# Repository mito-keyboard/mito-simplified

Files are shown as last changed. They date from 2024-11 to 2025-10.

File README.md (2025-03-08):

# Mito PCB

The pcb for my [custom keyboard](https://github.com/KOEGlike/mito)

## Sponsor

Much thanks to pcbway for sponsoring this project, the video is in the making, stay tuned! The PCBs and stencil are very high quality!!

## Gallery

back of pcb
back of pcb with nrf52833

## Name

Inspired by the mitosis of cells

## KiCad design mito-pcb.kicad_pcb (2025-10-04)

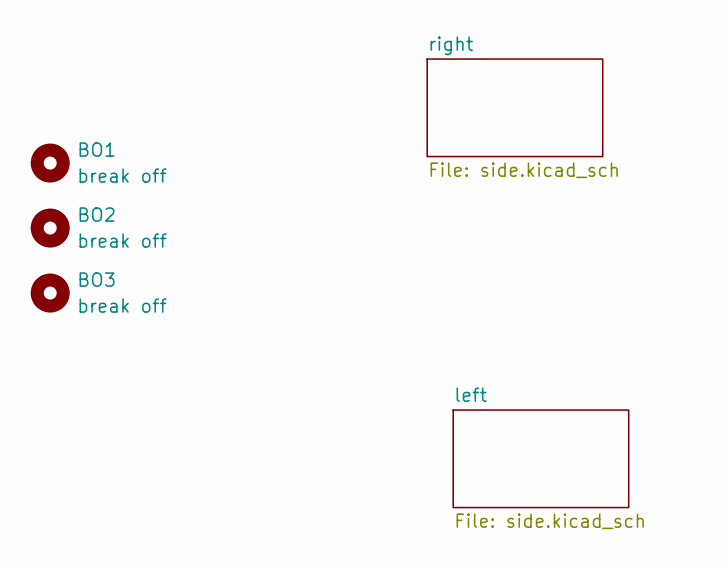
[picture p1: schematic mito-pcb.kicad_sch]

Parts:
BO1, BO2, BO3: break off; mouse-bite-2mm-slot

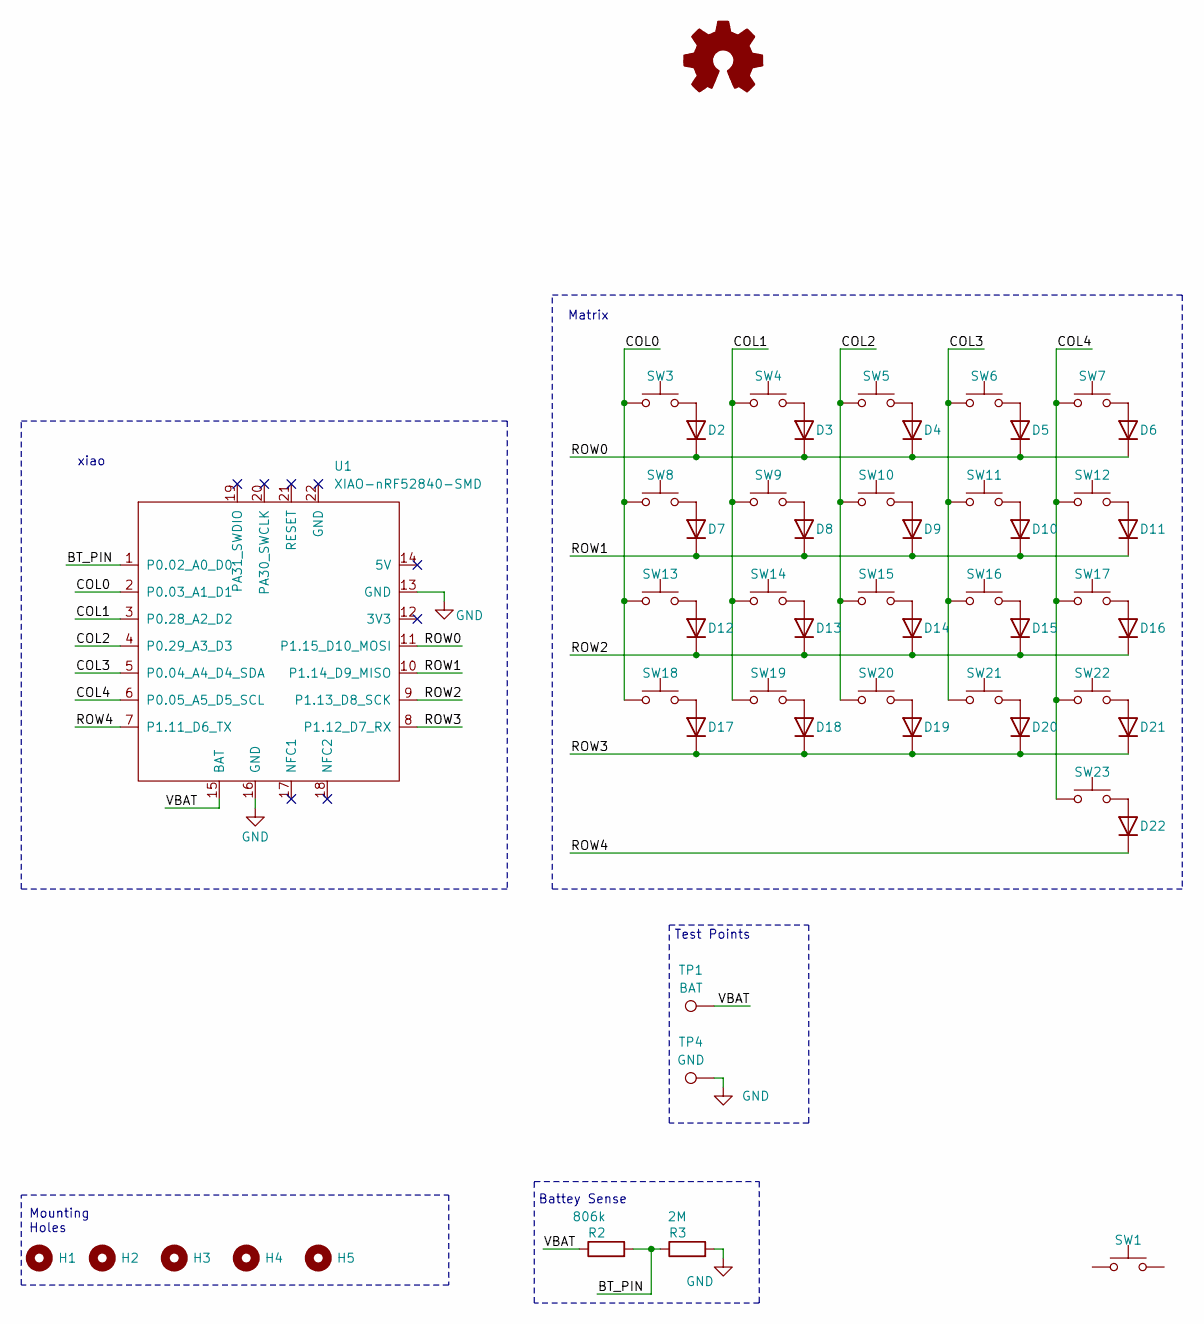
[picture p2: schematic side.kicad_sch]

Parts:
D2, D3, D4, D5, D6, D7, D8, D9, D10, D11, D12, D13, D14, D15, D16, D17, D18, D19, D20, D21, D22: 1N5819; D_SOD-123; LCSC C963381
H1, H2, H3, H4, H5: MountingHole; MountingHole_2mm
LOGO1: Logo_Open_Hardware_Small; BM logo
R2: 806k; R_0805_2012Metric; LCSC C3016043
R3: 2M; R_0805_2012Metric; LCSC C11512
SW1, SW3, SW4, SW5, SW6, SW7, SW8, SW9, SW10, SW11, SW12, SW13, SW14, SW15, SW16, SW17, SW18, SW19, SW20, SW21, SW22, SW23: SW_Push; SW_choc_v1_HS_CPG135001S30_1u; LCSC C5333465
TP1: BAT; TestPoint_Pad_D2.0mm
TP4: GND; TestPoint_Pad_D2.0mm
U1: XIAO-nRF52840-SMD; modified-XIAO-nRF52840-SMD

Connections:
/left/BT_PIN: R2.2, R3.1, U1.1 (P0.02_A0_D0)
/left/COL0: SW3.1, SW8.1, SW13.1, SW18.1, U1.2 (P0.03_A1_D1)
/left/COL1: SW4.1, SW9.1, SW14.1, SW19.1, U1.3 (P0.28_A2_D2)
/left/COL2: SW5.1, SW10.1, SW15.1, SW20.1, U1.4 (P0.29_A3_D3)
/left/COL3: SW6.1, SW11.1, SW16.1, SW21.1, U1.5 (P0.04_A4_D4_SDA)
/left/COL4: SW7.1, SW12.1, SW17.1, SW22.1, SW23.1, U1.6 (P0.05_A5_D5_SCL)
/left/ROW0: D2.1 (K), D3.1 (K), D4.1 (K), D5.1 (K), D6.1 (K), U1.11 (P1.15_D10_MOSI)
/left/ROW1: D7.1 (K), D8.1 (K), D9.1 (K), D10.1 (K), D11.1 (K), U1.10 (P1.14_D9_MISO)
/left/ROW2: D12.1 (K), D13.1 (K), D14.1 (K), D15.1 (K), D16.1 (K), U1.9 (P1.13_D8_SCK)
/left/ROW3: D17.1 (K), D18.1 (K), D19.1 (K), D20.1 (K), D21.1 (K), U1.8 (P1.12_D7_RX)
/left/ROW4: D22.1 (K), U1.7 (P1.11_D6_TX)
/left/VBAT: R2.1, TP1.1, U1.15 (BAT)
GND: R3.2, TP4.1, U1.13 (GND), U1.16 (GND); also elsewhere on the board
unnamed: D2.2 (A), SW3.2
unnamed: D3.2 (A), SW4.2
unnamed: D4.2 (A), SW5.2
unnamed: D5.2 (A), SW6.2
unnamed: D6.2 (A), SW7.2
unnamed: D7.2 (A), SW8.2
unnamed: D8.2 (A), SW9.2
unnamed: D9.2 (A), SW10.2
unnamed: D10.2 (A), SW11.2
unnamed: D11.2 (A), SW12.2
unnamed: D12.2 (A), SW13.2
unnamed: D13.2 (A), SW14.2
unnamed: D14.2 (A), SW15.2
unnamed: D15.2 (A), SW16.2
unnamed: D16.2 (A), SW17.2
unnamed: D17.2 (A), SW18.2
unnamed: D18.2 (A), SW19.2
unnamed: D19.2 (A), SW20.2
unnamed: D20.2 (A), SW21.2
unnamed: D21.2 (A), SW22.2
unnamed: D22.2 (A), SW23.2

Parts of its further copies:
D44, D45, D46, D47, D48, D49, D50, D51, D52, D53, D54, D55, D56, D57, D58, D59, D60, D61, D62, D63, D64: 1N5819; D_SOD-123; LCSC C963381
H6, H7, H8, H9, H10: MountingHole; MountingHole_2mm
R9: 806k; R_0805_2012Metric; LCSC C3016043
R10: 2M; R_0805_2012Metric; LCSC C11512
SW26, SW27, SW28, SW29, SW30, SW31, SW32, SW33, SW34, SW35, SW36, SW37, SW38, SW39, SW40, SW41, SW42, SW43, SW44, SW45, SW46: SW_Push; SW_choc_v1_HS_CPG135001S30_1u; LCSC C5333465
TP2: BAT; TestPoint_Pad_D2.0mm
TP8: GND; TestPoint_Pad_D2.0mm
U3: XIAO-nRF52840-SMD; modified-XIAO-nRF52840-SMD

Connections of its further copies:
/right/BT_PIN: R9.2, R10.1, U3.1 (P0.02_A0_D0)
/right/COL0: SW26.1, SW31.1, SW36.1, SW41.1, U3.2 (P0.03_A1_D1)
/right/COL1: SW27.1, SW32.1, SW37.1, SW42.1, U3.3 (P0.28_A2_D2)
/right/COL2: SW28.1, SW33.1, SW38.1, SW43.1, U3.4 (P0.29_A3_D3)
/right/COL3: SW29.1, SW34.1, SW39.1, SW44.1, U3.5 (P0.04_A4_D4_SDA)
/right/COL4: SW30.1, SW35.1, SW40.1, SW45.1, SW46.1, U3.6 (P0.05_A5_D5_SCL)
/right/ROW0: D44.1 (K), D45.1 (K), D46.1 (K), D47.1 (K), D48.1 (K), U3.11 (P1.15_D10_MOSI)
/right/ROW1: D49.1 (K), D50.1 (K), D51.1 (K), D52.1 (K), D53.1 (K), U3.10 (P1.14_D9_MISO)
/right/ROW2: D54.1 (K), D55.1 (K), D56.1 (K), D57.1 (K), D58.1 (K), U3.9 (P1.13_D8_SCK)
/right/ROW3: D59.1 (K), D60.1 (K), D61.1 (K), D62.1 (K), D63.1 (K), U3.8 (P1.12_D7_RX)
/right/ROW4: D64.1 (K), U3.7 (P1.11_D6_TX)
/right/VBAT: R9.1, TP2.1, U3.15 (BAT)
GND: R10.2, TP8.1, U3.13 (GND), U3.16 (GND); also elsewhere on the board
unnamed: D44.2 (A), SW26.2
unnamed: D45.2 (A), SW27.2
unnamed: D46.2 (A), SW28.2
unnamed: D47.2 (A), SW29.2
unnamed: D48.2 (A), SW30.2
unnamed: D49.2 (A), SW31.2
unnamed: D50.2 (A), SW32.2
unnamed: D51.2 (A), SW33.2
unnamed: D52.2 (A), SW34.2
unnamed: D53.2 (A), SW35.2
unnamed: D54.2 (A), SW36.2
unnamed: D55.2 (A), SW37.2
unnamed: D56.2 (A), SW38.2
unnamed: D57.2 (A), SW39.2
unnamed: D58.2 (A), SW40.2
unnamed: D59.2 (A), SW41.2
unnamed: D60.2 (A), SW42.2
unnamed: D61.2 (A), SW43.2
unnamed: D62.2 (A), SW44.2
unnamed: D63.2 (A), SW45.2
unnamed: D64.2 (A), SW46.2

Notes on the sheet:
Battey Sense
Matrix
Mounting Holes
Test Points
xiao

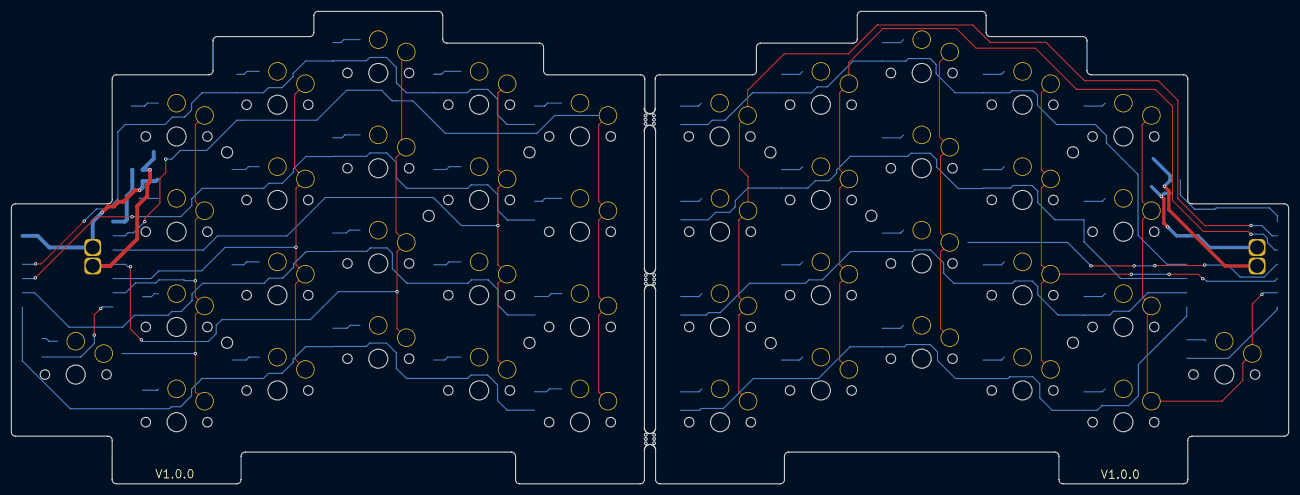
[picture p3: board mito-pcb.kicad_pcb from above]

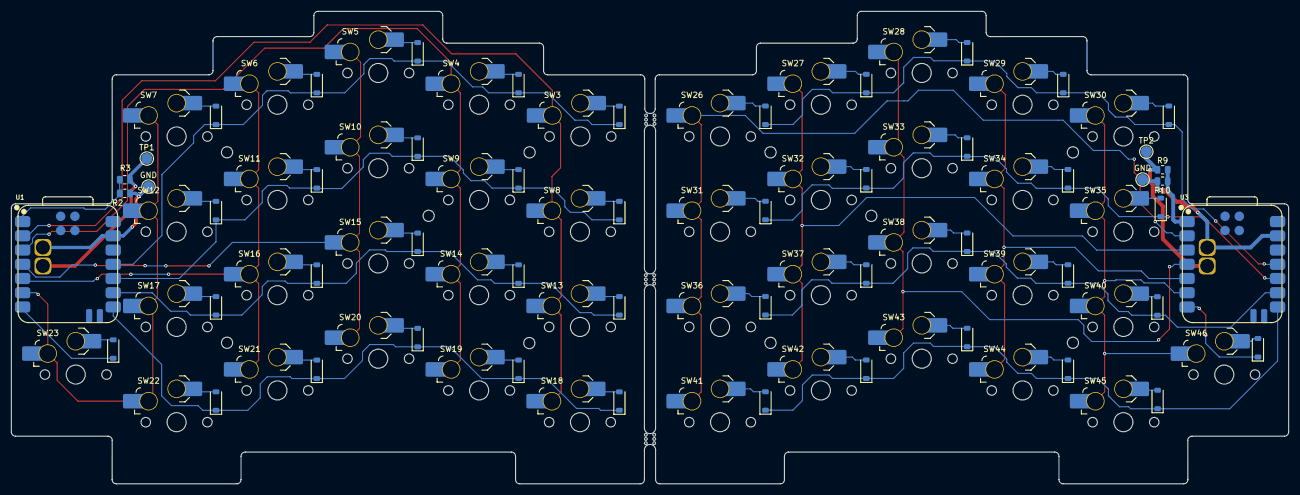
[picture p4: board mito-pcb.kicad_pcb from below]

Board: 2 copper layers, 228.0 x 84.3 mm, 107 parts (99 on the bottom side), 67 nets.

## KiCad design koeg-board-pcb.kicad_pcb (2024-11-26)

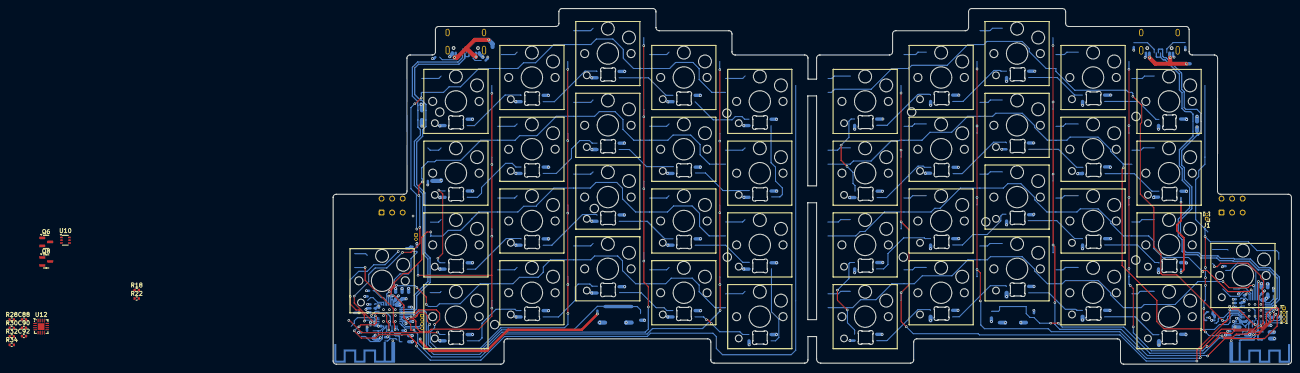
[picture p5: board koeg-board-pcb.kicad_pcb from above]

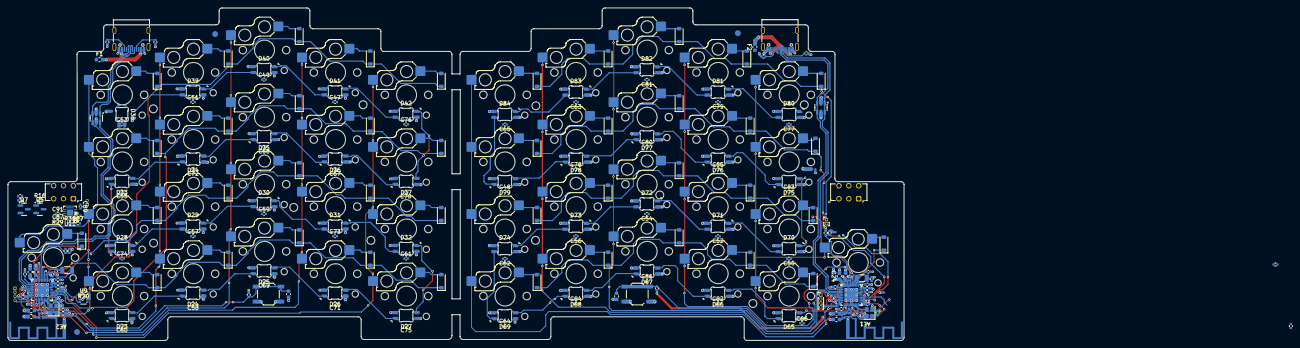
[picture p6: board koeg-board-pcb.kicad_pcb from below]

Board: 4 copper layers, 227.1 x 84.3 mm, 277 parts (215 on the bottom side), 173 nets.

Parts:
AE1: PCB_Antenna; flipped_pcb_antenna
AE2: PCB_Antenna; pcb_antenna
C2, C18: 100nF; C_0603_1608Metric
C4, C20, C41, C42, C43, C44, C47, C48, C49, C50, C51, C52, C53, C54, C55, C56, C57, C58, C59, C60, C61, C62, C63, C64, C65, C66, C67, C68, C69, C70, C71, C72, C73, C74, C75, C76, C77, C78, C79, C80, C81, C82, C83, C84, C85, C86: 100nF; C_0402_1005Metric
C5, C21: 100pF; C_0402_1005Metric
C6, C22: 820pF; C_0402_1005Metric
C7, C23, C39, C40: 1uF; C_0402_1005Metric
C9, C25, C87, C88, C89, C90, C91, C92: 4.7uF; C_0402_1005Metric
C10, C19, C24, C26: 4.7uF; C_0603_1608Metric
C11, C12, C15, C16, C27, C28, C31, C32: 12pF; C_0402_1005Metric
C13, C29: 1pF; C_0603_1608Metric
C14, C30: 1.2pF; C_0603_1608Metric
D2, D3, D4, D5, D6, D7, D8, D9, D10, D11, D12, D13, D14, D15, D16, D17, D18, D19, D20, D21, D22, D44, D45, D46, D47, D48, D49, D50, D51, D52, D53, D54, D55, D56, D57, D58, D59, D60, D61, D62, D63, D64: 1N5819; D_SOD-123
D23, D24, D25, D26, D27, D28, D29, D30, D31, D32, D33, D34, D35, D36, D37, D38, D39, D40, D41, D42, D65, D66, D67, D68, D69, D70, D71, D72, D73, D74, D75, D76, D77, D78, D79, D80, D81, D82, D83, D84: SK6812MINI-E; LED_6028R
F1, F2: 500mA; Fuse_0603_1608Metric
FID1, FID2, FID3: Fiducial; Fiducial_1.5mm_Mask3mm
H1, H2, H3, H4, H5, H6, H7, H8, H9, H10: MountingHole; MountingHole_2mm
J1, J4: Conn_01x02; PinHeader_1x02_P1.00mm_Vertical
J2, J5: SWD_Connector; PinHeader_1x04_P1.00mm_Vertical
J3, J6: USB_C_Receptacle_USB2.0_16P; USB_C_Receptacle_G-Switch_GT-USB-7010ASV
L4, L9: 4.7nH; L_0402_1005Metric
L5, L10: 2.2nH; L_0402_1005Metric
Q5, Q6: AO3401A; SOT-23
Q7, Q8: 2N7002; SOT-23
R1, R8: 100K; R_0402_1005Metric
R2, R9: 806k; R_0402_1005Metric
R3, R10: 2M; R_0402_1005Metric
R4, R5, R11, R12: 5.1k; R_0402_1005Metric
R6, R7: 100R; R_0402_1005Metric
R13, R14, R16, R18, R20, R22: 10k; R_0402_1005Metric
R27, R28: 3.9k; R_0402_1005Metric
R29, R30, R31, R32, R33, R34: 1.5k; R_0402_1005Metric
SW1, SW24: Reset Button; SW_SPST_TL3342
SW2, SW25: SW_On_Off; SW_CK_JS202011AQN_DPDT_Angled
SW3, SW4, SW5, SW6, SW7, SW8, SW9, SW10, SW11, SW12, SW13, SW14, SW15, SW16, SW17, SW18, SW19, SW20, SW21, SW22, SW26, SW27, SW28, SW29, SW30, SW31, SW32, SW33, SW34, SW35, SW36, SW37, SW38, SW39, SW40, SW41, SW42, SW43, SW44, SW45: SW_Push; SW_Hotswap_Kailh_Choc_V1V2_1.00u
SW23, SW46: SW_Push; SW_Hotswap_Kailh_Choc_V1V2_1.75u_90deg
U2, U5: USBLC6-2SC6; SOT-23-6
U7, U8: nRF52833_QDxx; QFN-40-1EP_5x5mm_P0.4mm_EP3.6x3.6mm
U9, U10: TXB0101DCK; SOT-363_SC-70-6
U11, U12: BQ24075RGT; VQFN-16-1EP_3x3mm_P0.5mm_EP1.6x1.6mm
Y1, Y2: 32MHz; Crystal_SMD_2520-4Pin_2.5x2.0mm
Y3, Y4: 32.768 kHz; Crystal_SMD_3215-2Pin_3.2x1.5mm

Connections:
/left/ANT: AE2.2 (PCB_Trace), C13.2, L4.1, L5.2, U7.24 (ANT)
/left/BT_PIN: R2.2, R3.1, U7.6 (P1.09)
/left/CC1: J3.A5 (CC1), R4.1
/left/CC2: J3.B5 (CC2), R5.1
/left/COL0: SW3.2, SW8.2, SW13.2, SW18.2, U7.34 (AIN5/P0.29)
/left/COL1: SW4.2, SW9.2, SW14.2, SW19.2, U7.7 (P0.11)
/left/COL2: SW5.2, SW10.2, SW15.2, SW20.2, U7.14 (P0.15)
/left/COL3: SW6.2, SW11.2, SW16.2, SW21.2, U7.15 (P0.17)
/left/COL4: SW7.2, SW12.2, SW17.2, SW22.2, SW23.2, U7.17 (P0.20)
/left/DEC1: C4.1, U7.1 (DEC1)
/left/DEC3: C5.1, U7.27 (DEC3)
/left/DEC4-6: C7.1, U7.26 (DEC6), U7.38 (DEC4)
/left/DEC5: C6.1, U7.21 (DEC5)
/left/DECUSB: C9.1, U7.11 (DECUSB)
/left/LED_EN: R6.1, U7.35 (AIN6/P0.30)
/left/LED_PIN: U7.33 (AIN4/P0.28), U9.3 (A)
/left/RESET: C2.2, R1.2, SW1.1, U7.16 (P0.18/~RESET)
/left/ROW0: D2.1 (K), D3.1 (K), D4.1 (K), D5.1 (K), D6.1 (K), U7.32 (AIN0/P0.02)
/left/ROW1: D7.1 (K), D8.1 (K), D9.1 (K), D10.1 (K), D11.1 (K), U7.31 (AIN1/P0.03)
/left/ROW2: D12.1 (K), D13.1 (K), D14.1 (K), D15.1 (K), D16.1 (K), U7.4 (AIN2/P0.04)
/left/ROW3: D17.1 (K), D18.1 (K), D19.1 (K), D20.1 (K), D21.1 (K), U7.5 (AIN3/P0.05)
/left/ROW4: D22.1 (K), U7.22 (NFC1/P0.09)
/left/SWDCLK: J2.4, U7.20 (SWDCLK)
/left/SWDIO: J2.3, U7.19 (SWDIO)
/left/USB_D+: J3.A6 (D+), J3.B6 (D+), U2.3 (I/O2), U2.4 (I/O2), U7.13 (D+)
/left/USB_D-: J3.A7 (D-), J3.B7 (D-), U2.1 (I/O1), U2.6 (I/O1), U7.12 (D-)
/left/VBAT: C89.2, J1.1, R2.1, U11.2 (BAT), U11.3 (BAT)
/left/VBUS: C87.2, F1.1, U2.5 (VBUS), U11.13 (IN)
/left/VSW: C19.1, Q5.3 (D), R16.2, SW2.2 (B), U7.9 (VDDH), U7.10 (VBUS), U9.6 (V_{CCB}), U11.6 (EN1)
/left/V_SYS: C10.2, C39.2, C41.2, C43.2, J2.2, R1.1, R20.2, U7.8 (VDD), U7.18 (VDD), U7.30 (VDD), U7.40 (VDD), U9.1 (V_{CCA})
/left/XC1: C11.1, U7.28 (XC1), Y1.1
/left/XC2: C12.1, U7.29 (XC2), Y1.3
/left/XL1: C31.2, U7.2 (XL1/P0.00), Y3.2
/left/XL2: C15.2, U7.3 (XL2/P0.01), Y3.1
/left/leds/DATA: D23.3 (DIN), U9.4 (B)
/left/leds/LED_PWR: C47.2, C49.2, C51.2, C53.2, C55.2, C57.2, C58.2, C59.2, C60.2, C61.2, C67.2, C68.2, C69.2, C70.2, C71.2, C72.2, C73.2, C74.2, C75.2, C76.2, D23.1 (VDD), D24.1 (VDD), D25.1 (VDD), D26.1 (VDD), D27.1 (VDD), D28.1 (VDD), D29.1 (VDD), D30.1 (VDD), D31.1 (VDD), D32.1 (VDD), D33.1 (VDD), D34.1 (VDD), D35.1 (VDD), D36.1 (VDD), D37.1 (VDD), D38.1 (VDD), D39.1 (VDD), D40.1 (VDD), D41.1 (VDD), D42.1 (VDD), Q5.2 (S)
/left/power/ILIM: R29.1, U11.12 (ILIM)
/left/power/ISET: R27.1, U11.16 (ISET)
/left/power/REG-OUT: C91.2, SW2.1 (A), U11.10 (OUT), U11.11 (OUT)
/left/power/TMR: R31.1, U11.14 (TMR)
/left/power/TS: R33.2, U11.1 (TS)
/right/ANT: AE1.2 (PCB_Trace), C29.2, L9.1, L10.2, U8.24 (ANT)
/right/BT_PIN: R9.2, R10.1, U8.6 (P1.09)
/right/CC1: J6.A5 (CC1), R11.1
/right/CC2: J6.B5 (CC2), R12.1
/right/COL0: SW26.2, SW31.2, SW36.2, SW41.2, U8.34 (AIN5/P0.29)
/right/COL1: SW27.2, SW32.2, SW37.2, SW42.2, U8.7 (P0.11)
/right/COL2: SW28.2, SW33.2, SW38.2, SW43.2, U8.14 (P0.15)
/right/COL3: SW29.2, SW34.2, SW39.2, SW44.2, U8.15 (P0.17)
/right/COL4: SW30.2, SW35.2, SW40.2, SW45.2, SW46.2, U8.17 (P0.20)
/right/DEC1: C20.1, U8.1 (DEC1)
/right/DEC3: C21.1, U8.27 (DEC3)
/right/DEC4-6: C23.1, U8.26 (DEC6), U8.38 (DEC4)
/right/DEC5: C22.1, U8.21 (DEC5)
/right/DECUSB: C25.1, U8.11 (DECUSB)
/right/LED_EN: R7.1, U8.35 (AIN6/P0.30)
/right/LED_PIN: U8.33 (AIN4/P0.28), U10.3 (A)
/right/RESET: C18.2, R8.2, SW24.1, U8.16 (P0.18/~RESET)
/right/ROW0: D44.1 (K), D45.1 (K), D46.1 (K), D47.1 (K), D48.1 (K), U8.32 (AIN0/P0.02)
/right/ROW1: D49.1 (K), D50.1 (K), D51.1 (K), D52.1 (K), D53.1 (K), U8.31 (AIN1/P0.03)
/right/ROW2: D54.1 (K), D55.1 (K), D56.1 (K), D57.1 (K), D58.1 (K), U8.4 (AIN2/P0.04)
/right/ROW3: D59.1 (K), D60.1 (K), D61.1 (K), D62.1 (K), D63.1 (K), U8.5 (AIN3/P0.05)
/right/ROW4: D64.1 (K), U8.22 (NFC1/P0.09)
/right/SWDCLK: J5.4, U8.20 (SWDCLK)
/right/SWDIO: J5.3, U8.19 (SWDIO)
/right/USB_D+: J6.A6 (D+), J6.B6 (D+), U5.3 (I/O2), U5.4 (I/O2), U8.13 (D+)
/right/USB_D-: J6.A7 (D-), J6.B7 (D-), U5.1 (I/O1), U5.6 (I/O1), U8.12 (D-)
/right/VBAT: C90.2, J4.1, R9.1, U12.2 (BAT), U12.3 (BAT)
/right/VBUS: C88.2, F2.1, U5.5 (VBUS), U12.13 (IN)
/right/VSW: C24.1, Q6.3 (D), R18.2, SW25.2 (B), U8.9 (VDDH), U8.10 (VBUS), U10.6 (V_{CCB}), U12.6 (EN1)
/right/V_SYS: C26.2, C40.2, C42.2, C44.2, J5.2, R8.1, R22.2, U8.8 (VDD), U8.18 (VDD), U8.30 (VDD), U8.40 (VDD), U10.1 (V_{CCA})
/right/XC1: C27.1, U8.28 (XC1), Y2.1
/right/XC2: C28.1, U8.29 (XC2), Y2.3
/right/XL1: C32.2, U8.2 (XL1/P0.00), Y4.2
/right/XL2: C16.2, U8.3 (XL2/P0.01), Y4.1
/right/leds/DATA: D65.3 (DIN), U10.4 (B)
/right/leds/LED_PWR: C48.2, C50.2, C52.2, C54.2, C56.2, C62.2, C63.2, C64.2, C65.2, C66.2, C77.2, C78.2, C79.2, C80.2, C81.2, C82.2, C83.2, C84.2, C85.2, C86.2, D65.1 (VDD), D66.1 (VDD), D67.1 (VDD), D68.1 (VDD), D69.1 (VDD), D70.1 (VDD), D71.1 (VDD), D72.1 (VDD), D73.1 (VDD), D74.1 (VDD), D75.1 (VDD), D76.1 (VDD), D77.1 (VDD), D78.1 (VDD), D79.1 (VDD), D80.1 (VDD), D81.1 (VDD), D82.1 (VDD), D83.1 (VDD), D84.1 (VDD), Q6.2 (S)
/right/power/ILIM: R30.1, U12.12 (ILIM)
/right/power/ISET: R28.1, U12.16 (ISET)
/right/power/REG-OUT: C92.2, SW25.1 (A), U12.10 (OUT), U12.11 (OUT)
/right/power/TMR: R32.1, U12.14 (TMR)
/right/power/TS: R34.2, U12.1 (TS)
GND: AE1.1 (FEED), AE2.1 (FEED), C2.1, C4.2, C5.2, C6.2, C7.2, C9.2, C10.1, C11.2, C12.2, C13.1, C14.2, C15.1, C16.1, C18.1, C19.2, C20.2, C21.2, C22.2, C23.2, C24.2, C25.2, C26.1, C27.2, C28.2, C29.1, C30.2, C31.1, C32.1, C39.1, C40.1, C41.1, C42.1, C43.1, C44.1, C47.1, C48.1, C49.1, C50.1, C51.1, C52.1, C53.1, C54.1, C55.1, C56.1, C57.1, C58.1, C59.1, C60.1, C61.1, C62.1, C63.1, C64.1, C65.1, C66.1, C67.1, C68.1, C69.1, C70.1, C71.1, C72.1, C73.1, C74.1, C75.1, C76.1, C77.1, C78.1, C79.1, C80.1, C81.1, C82.1, C83.1, C84.1, C85.1, C86.1, C87.1, C88.1, C89.1, C90.1, C91.1, C92.1, D23.4 (VSS), D24.4 (VSS), D25.4 (VSS), D26.4 (VSS), D27.4 (VSS), D28.4 (VSS), D29.4 (VSS), D30.4 (VSS), D31.4 (VSS), D32.4 (VSS), D33.4 (VSS), D34.4 (VSS), D35.4 (VSS), D36.4 (VSS), D37.4 (VSS), D38.4 (VSS), D39.4 (VSS), D40.4 (VSS), D41.4 (VSS), D42.4 (VSS), D65.4 (VSS), D66.4 (VSS), D67.4 (VSS), D68.4 (VSS), D69.4 (VSS), D70.4 (VSS), D71.4 (VSS), D72.4 (VSS), D73.4 (VSS), D74.4 (VSS), D75.4 (VSS), D76.4 (VSS), D77.4 (VSS), D78.4 (VSS), D79.4 (VSS), D80.4 (VSS), D81.4 (VSS), D82.4 (VSS), D83.4 (VSS), D84.4 (VSS), J1.2, J2.1, J3.A1 (GND), J3.A12 (GND), J3.B1 (GND), J3.B12 (GND), J4.2, J5.1, J6.A1 (GND), J6.A12 (GND), J6.B1 (GND), J6.B12 (GND), Q7.2 (S), Q8.2 (S), R3.2, R4.2, R5.2, R10.2, R11.2, R12.2, R13.1, R14.1, R27.2, R28.2, R29.2, R30.2, R31.2, R32.2, R33.1, R34.1, SW1.2, SW24.2, U2.2 (GND), U5.2 (GND), U7.25 (VSS_PA), U7.37 (VSS), U7.41 (VSS), U8.25 (VSS_PA), U8.37 (VSS), U8.41 (VSS), U9.2 (GND), U10.2 (GND), U11.4 (~CE), U11.5 (EN2), U11.8 (VSS), U11.15 (SYSOFF), U11.17 (VSS), U12.4 (~CE), U12.5 (EN2), U12.8 (VSS), U12.15 (SYSOFF), U12.17 (VSS), Y1.2, Y1.4, Y2.2, Y2.4
unnamed: C14.1, L4.2, L5.1
unnamed: C30.1, L9.2, L10.1
unnamed: D2.2 (A), SW3.1
unnamed: D3.2 (A), SW4.1
unnamed: D4.2 (A), SW5.1
unnamed: D5.2 (A), SW6.1
unnamed: D6.2 (A), SW7.1
unnamed: D7.2 (A), SW8.1
unnamed: D8.2 (A), SW9.1
unnamed: D9.2 (A), SW10.1
unnamed: D10.2 (A), SW11.1
unnamed: D11.2 (A), SW12.1
unnamed: D12.2 (A), SW13.1
unnamed: D13.2 (A), SW14.1
unnamed: D14.2 (A), SW15.1
unnamed: D15.2 (A), SW16.1
unnamed: D16.2 (A), SW17.1
unnamed: D17.2 (A), SW18.1
unnamed: D18.2 (A), SW19.1
unnamed: D19.2 (A), SW20.1
unnamed: D20.2 (A), SW21.1
unnamed: D21.2 (A), SW22.1
unnamed: D22.2 (A), SW23.1
unnamed: D23.2 (DOUT), D24.3 (DIN)
unnamed: D24.2 (DOUT), D25.3 (DIN)
unnamed: D25.2 (DOUT), D26.3 (DIN)
unnamed: D26.2 (DOUT), D27.3 (DIN)
unnamed: D27.2 (DOUT), D32.3 (DIN)
unnamed: D28.3 (DIN), D29.2 (DOUT)
unnamed: D28.2 (DOUT), D33.3 (DIN)
unnamed: D29.3 (DIN), D30.2 (DOUT)
unnamed: D30.3 (DIN), D31.2 (DOUT)
unnamed: D31.3 (DIN), D32.2 (DOUT)
unnamed: D33.2 (DOUT), D34.3 (DIN)
unnamed: D34.2 (DOUT), D35.3 (DIN)
unnamed: D35.2 (DOUT), D36.3 (DIN)
unnamed: D36.2 (DOUT), D37.3 (DIN)
unnamed: D37.2 (DOUT), D42.3 (DIN)
unnamed: D38.3 (DIN), D39.2 (DOUT)
unnamed: D39.3 (DIN), D40.2 (DOUT)
unnamed: D40.3 (DIN), D41.2 (DOUT)
unnamed: D41.3 (DIN), D42.2 (DOUT)
unnamed: D44.2 (A), SW26.1
unnamed: D45.2 (A), SW27.1
unnamed: D46.2 (A), SW28.1
unnamed: D47.2 (A), SW29.1
unnamed: D48.2 (A), SW30.1
unnamed: D49.2 (A), SW31.1
unnamed: D50.2 (A), SW32.1
unnamed: D51.2 (A), SW33.1
unnamed: D52.2 (A), SW34.1
unnamed: D53.2 (A), SW35.1
unnamed: D54.2 (A), SW36.1
unnamed: D55.2 (A), SW37.1
unnamed: D56.2 (A), SW38.1
unnamed: D57.2 (A), SW39.1
unnamed: D58.2 (A), SW40.1
unnamed: D59.2 (A), SW41.1
unnamed: D60.2 (A), SW42.1
unnamed: D61.2 (A), SW43.1
unnamed: D62.2 (A), SW44.1
unnamed: D63.2 (A), SW45.1
unnamed: D64.2 (A), SW46.1
unnamed: D65.2 (DOUT), D66.3 (DIN)
unnamed: D66.2 (DOUT), D67.3 (DIN)
unnamed: D67.2 (DOUT), D68.3 (DIN)
unnamed: D68.2 (DOUT), D69.3 (DIN)
unnamed: D69.2 (DOUT), D74.3 (DIN)
unnamed: D70.3 (DIN), D71.2 (DOUT)
unnamed: D70.2 (DOUT), D75.3 (DIN)
unnamed: D71.3 (DIN), D72.2 (DOUT)
unnamed: D72.3 (DIN), D73.2 (DOUT)
unnamed: D73.3 (DIN), D74.2 (DOUT)
unnamed: D75.2 (DOUT), D76.3 (DIN)
unnamed: D76.2 (DOUT), D77.3 (DIN)
unnamed: D77.2 (DOUT), D78.3 (DIN)
unnamed: D78.2 (DOUT), D79.3 (DIN)
unnamed: D79.2 (DOUT), D84.3 (DIN)
unnamed: D80.3 (DIN), D81.2 (DOUT)
unnamed: D81.3 (DIN), D82.2 (DOUT)
unnamed: D82.3 (DIN), D83.2 (DOUT)
unnamed: D83.3 (DIN), D84.2 (DOUT)
unnamed: F1.2, J3.A4 (VBUS), J3.A9 (VBUS), J3.B4 (VBUS), J3.B9 (VBUS)
unnamed: F2.2, J6.A4 (VBUS), J6.A9 (VBUS), J6.B4 (VBUS), J6.B9 (VBUS)
unnamed: Q5.1 (G), Q7.3 (D), R16.1
unnamed: Q6.1 (G), Q8.3 (D), R18.1
unnamed: Q7.1 (G), R6.2, R13.2
unnamed: Q8.1 (G), R7.2, R14.2
unnamed: R20.1, U9.5 (OE)
unnamed: R22.1, U10.5 (OE)

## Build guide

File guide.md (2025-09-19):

# Wireless split

Hii! Do you not want to get carpal tunnel? Or just think that split keyboard are cool? Then you are in the right place!

In this guide you will be learning how to make a wireless split keyboard

This guide is meant to be an extension to the [hackpad guide](https://hackpad.hackclub.com/guide), so if you are a total beginner to keyboards/electronics read that first, and then come back here :)

In this tutorial we a going to use the same form factor board as in the hackpad tutorial, but with different internals, instead of a rp2040 it has a nrf52840 chip inside, which has wireless capabilities.

## Installing Libraries

After you created the kicad project, we need to install some libraries. We will be installing the same OPL libraries as in the hackpad tutorial, here is the [link](https://hackpad.hackclub.com/guide#pcb_design) for that section.

Unlike in the hackpad tutorial, where we use the official seeed footprints, this time we need to install install a custom footprint based on the official ones, because the battery charging pins are on the bottom of the board, which we will be using to charge the battery, that are not accessible if we use the official footprints.

You can download it from [github](https://github.com/mito-keyboard/mito-simplified/blob/main/modified-XIAO-nRF52840-SMD.kicad_mod), move it into you KiCad project folder, and add it like a the opl library.

We also need to download the library for the switches, we will be using [marbastlib](https://github.com/ebastler/marbastlib), you can find the installation instructions in the repo

Also instal [panelization.pretty](https://github.com/madworm/Panelization.pretty) for mousebites

## Schematic

Now we can start creating our schematic.

### Sheets

Because we are creating a split, we esantilay want to have to same circuit for both sides, but not the same layout. We can achieve this by using hierarchical sheets. This way the circuitry we make will be duplicated

To create a hierarchical sheet click on this on the right sidebar or press <kbd>S</kbd>

image of sheets icon

Now draw a rectangle and left click, a popup should appear:

image of popup

Change the `Sheetname` to `left`, and the `Sheetfile` to `side.kicad_sch`, and click ok

Now create another sheet, set `Sheetfile` to `side.kicad_sch`, but the `Sheetname` to `right`.

Your root sheet look something like this:

image of root sheet

And your left side bar something like this:

image of left side bar

You can now double click on one of the sheet rectangle in the root sheet, or in the left side bar. You can now place down a switch for example, and navigate to the other sub/child sheet, you will notice that the switch that you placed down in the other sub sheet, is also in this sub sheet.

left sheet
right sheet

## Circuitry

Now finally we can start to design our keyboard!!!

Add the `XIAO-nRF52840-SMD` symbol:

symbol add xiao

a switch `SW_Push`:
symbol add switch

and a diode `D` (you will see later why we need this):
symbol add diode

### Keyboard Matrix

You may be wondering, why did we need to place down a diode???? You may also notice that the xiao doesn't have enough pins for a full half of a split keyboard. In comes the humble keyboard matrix, with it we only have to connect one pin per column and row, drastically reducing the number of pins needed for a keyboard.

The matrix works by giving power to each column one at a time, and checking which keys are pressed down in that column. We need diodes to prevent *ghosting*, where by pressing down one key, the keyboard detects more then one keypress. If you want you can read into [keyboard matrixes here](https://docs.qmk.fm/how_a_matrix_works)

For now all you need to know is that every key has its own diode, this is like one unit:

image of diode and button

You can now make a matrix out of these *units*, you have to connect the switches to the columns, and the diodes to the rows. In this example in one row I only have one button, which is for my thumb:

image of complete keyboard matrix

You may notice that there are *labels*, like `COL0`, `COL1`, etc. and `ROW0` and `ROW1`. You can place these using the <kbd>L</kbd> shortcut or from the right sidebar. We can use labels to clean up our schematic, instead of routing from our xiao to the column, we just place a label with the same name at the column and one at the xiao's pin:

image of label underlined

### Battery

Adding a battery is really easy, because the xiao already has battery management built in. We need to add two pads where the battery can be connected to the pcb. In this case I used two test points, one for negative side of the battery(aka ground), and for the live side (vbat):
battery test points 

And then connected `VBAT` to the `BAT` pin of the xiao
xiao with VBAT connected

#### Sensing the battery voltage

This is an optional feature, that lets you see from you computer how much juice is left in your keyboards

We can achieve this by using a voltage divider, basically two resistors that divides the battery voltage by an amount, so we can measure it with our xiao. It looks like this, make sure to use these values for the resistors:

voltage divider

And then add the corresponding label (`BT_PIN` in our my case) to the xiao, make sure that it is an analogue pin (has A* ate the end):

xiao with battery sense

### Mounting points

Add mounting point symbols to the left/right schematics

### Mousebites

You should add three mounting points to the root sheet, we will assign mousebite footprints to these later on

mounting symbols

## Footprints

Your done with you schematic!!! 

Here is how mine looks:
image of authors schematic

Now its time to assign some footprints! First, open the footprint assigner tool.

For the xiao assign the custom footprint that you downloaded earlier, its name should be `modified-XIAO-nRF52840-SMD`

For the buttons I used chalk hotswap sockets from `marbastlib`, but you can use any other keyswitch.

For the diodes I used `1N5819` which are SMD, so its a bit harder to solder, but I recommend them if you want a compact design, and don't want to place THT diodes not next to the switches,rather some other place on the PCB. The footprint for this is `Diode_SMD:D_SOD-123`

For the resistors I recommend `Resistor_SMD:R_0805_2012Metric`, but you can use any other package.

For the mousebites/breakoffs assign the `panelization:mouse-bite-5mm-slot` footprints

For the testpoints/battery pads I used `TestPoint:TestPoint_Pad_D2.0mm`, but you can use larger.

## PCB

This part is basically the same as hackpad, so layout, then routing, except for the mousebites. So in this section I will give some tips for laying out a split keyboard

Here is my final pcb:
pcb

### If the two half are symmetrical

then you should make the edge.cuts for one half, select all the edge.cuts, right click, and `flip horizontal`, and now you have two symmetrical edge.cuts

### Mousebites layout

You should find two flat side of you two pcbs, place the mousebites there, and edit the edge cuts so it matches the mousebites footprint template:

flat side with mousebites

## Firmware

You will have to use the [ZMK](https://zmk.dev/docs) firmware, ZMK has excellent documentation and tutorials, and it explains it better then I could. It has a learning curve, but there is no getting around that

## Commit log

2024-10-29 before auto route
    [koeg-board-pcb.kicad_pcb, koeg-board-pcb.kicad_sch, leds.kicad_sch]
2024-10-30 one side done
    [koeg-board-pcb.kicad_pcb, koeg-board-pcb.kicad_sch]
2024-10-31 reassigned basic components, now comes the leds
    [koeg-board-pcb.kicad_pcb, koeg-board-pcb.kicad_sch, leds.kicad_sch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]
2024-10-31 placed leds
    [koeg-board-pcb.kicad_pcb]
2024-10-31 routed left side
    [koeg-board-pcb.kicad_pcb, side.kicad_sch]
2024-11-02 placed right side
    [koeg-board-pcb.kicad_pcb, leds.kicad_sch, side.kicad_sch]
2024-11-02 routed right side, added filets
    [koeg-board-pcb.kicad_pcb]
2024-11-02 added propper brake offs
    [koeg-board-pcb.kicad_pcb, side.kicad_sch]
2024-11-02 idk what changed here
    [koeg-board-pcb.kicad_pcb]
2024-11-04 wired up the new votlage converter, removed small smd componenets
    [leds.kicad_sch, side.kicad_sch]
2024-11-09 placed components
    [koeg-board-pcb.kicad_pcb, leds.kicad_sch, side.kicad_sch]
2024-11-10 the right side still needs to be routed
    [koeg-board-pcb.kicad_pcb, koeg-board-pcb.kicad_sch, side.kicad_sch]
2024-11-10 chaned usb c footprint, flipped fiducials
    [koeg-board-pcb.kicad_pcb, side.kicad_sch]
2024-11-18 adding power and battery management
    [koeg-board-pcb.kicad_pcb, leds.kicad_sch, power.kicad_sch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]
2024-11-24 finished power circuit
    [koeg-board-pcb.kicad_pcb, koeg-board-pcb.kicad_sch, leds.kicad_sch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]
2024-11-24 added submodule instead of code for footprint library
2024-11-24 made schemtic look better
    [leds.kicad_sch, power.kicad_sch, side.kicad_sch]
2024-11-26 switched oout led footprint
    [koeg-board-pcb.kicad_pcb, leds.kicad_sch, power.kicad_sch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]
2024-11-26 reassigned refrences
    [leds.kicad_sch]
2024-11-26 updated some things
    [side.kicad_sch]
2024-11-26 added mousebites properly this time
    [koeg-board-pcb.kicad_sch, leds.kicad_sch, power.kicad_sch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]
2024-11-28 switched to chip antenna
    [koeg-board-pcb.kicad_sch, side.kicad_sch]
2024-11-29 added lcsc part numbers
    [leds.kicad_sch, power.kicad_sch, side.kicad_sch]
2024-11-30 idk what changed
    [side.kicad_sch]
2024-12-01 added test points
    [side.kicad_sch]
2024-12-01 removed unnecessary vias next to the led decoupling caps
2024-12-01 fixed fillzones
    [leds.kicad_sch, side.kicad_sch]
2024-12-02 upated routing of colums
    [side.kicad_sch]
2024-12-03 cleand up things
    [side.kicad_sch]
2024-12-03 removed silkscreen idenrifiers
2024-12-06 added logo, cleaned up traces
    [side.kicad_sch]
2024-12-06 checked schematic again, fixed bugs
    [power.kicad_sch, side.kicad_sch]
2024-12-13 removed prod folder, added version silkscreen, incrase no ground plane are around antenna
2024-12-13 0.09 mm to 0.1 mm clearnce pt.1
2024-12-13 pt2 of 0.09mm to 0.1mm
2024-12-13 pt3 of 0.09mm to 0.1mm clearace
2024-12-14 fixed edge cuts, switched to marbastlib switches
    [leds.kicad_sch, mito-pcb.kicad_sch, power.kicad_sch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]
2024-12-14 found more edge cute issues💀
2025-01-02 added missing 3d models
    i couldn't find the 3d model for the usb c port, so i used a similar one, the only problem is that the feet aren't in the same place as on the footprint, so it clips into the board
2025-02-01 new kicad version, added lcsc for the on/of switch
    [leds.kicad_sch, mito-pcb.kicad_sch, power.kicad_sch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]
2025-03-08 kicad did something
2025-03-22 fixed wrong resistor value for power management chip
    [power.kicad_sch]
2025-09-17 made progress, added xiao libray, removed almost all of the old schmeatic, started ot edit pcb
    [mito-pcb.kicad_sch, power.kicad_sch, side.kicad_sch]
2025-09-17 changed xioa footprint, edited edge cuts, layed out
    [mito-pcb.kicad_pcb, side.kicad_sch]
2025-09-18 routed left half
    [mito-pcb.kicad_pcb, side.kicad_sch]
2025-09-18 renamed the custom footprint
2025-09-18 worked on guide
    [side.kicad_sch]
2025-09-19 Refactor code structure for improved readability and maintainability
    [side.kicad_sch]
2025-10-04 routed other half,added models
    [mito-pcb.kicad_pcb]
